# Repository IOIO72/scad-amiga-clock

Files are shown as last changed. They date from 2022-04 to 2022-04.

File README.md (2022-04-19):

# Amiga Clock (3 June 2021)
by IOIO72 aka Tamio Patrick Honma (https://honma.de)

## Description

Amiga Clock is an adaptation of Clock V2.15 from Amiga Workbench 1.2.

You can attach this 3D print to a clock movement to experience the physical version of an iconic program from the digital past.

The model is customizable and can be adapted to any clockwork and size - down to wristwatches. It's even possible to print static versions of different time settings, i.e. to create opening times signs.

For those, who don't want to create a customized version, here's the clockwork, I used for this project:
https://www.amazon.de/gp/product/B08RNJ5SYK/

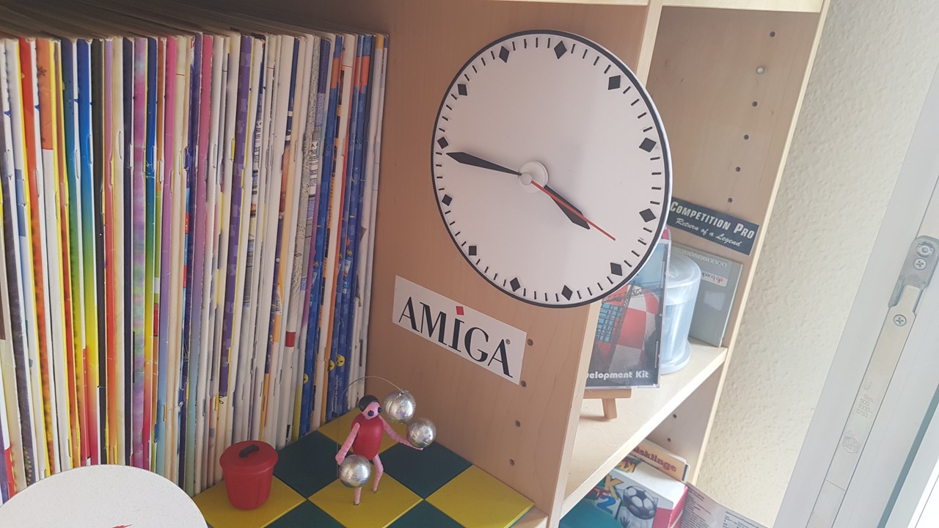
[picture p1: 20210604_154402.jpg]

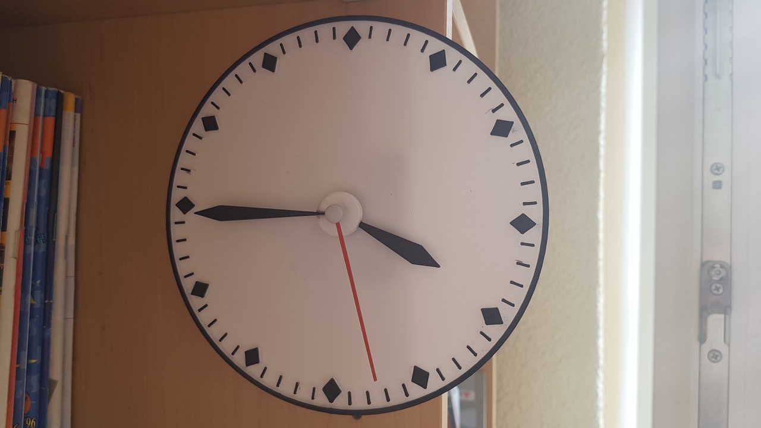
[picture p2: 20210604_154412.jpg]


### Where's the second hand?

Since the second hand has a small pin for mounting, it is not easy to print one that is accurate enough. The purchasable clockwork packages usually include a variety of hands from which you can choose. There should definitely be a second hand that is just a dash, like the one on the Amiga Clock. Use this second hand and paint it orange.

### Use OpenSCAD

1. **Download and install:** [OpenSCAD](http://openscad.org/) version 2021.01 or newer
2. **Download:** The *.scad file of this model.
3. **Start** OpenSCAD and **open** the *.scad file in it.
4. **Open the customizer** via the menu "Window/Customizer"

Now you can configure the model and use the `F5` key to render the preview of your changes.

#### Export your STL file

If you're done with your model settings, you can export the STL file:

1. Render the mesh by pressing the `F6` key.
2. Wait until the rendering is finished. This might take some minutes.
3. Export the STL file by pressing the `F7` key.

#### Optionally save your configuration

If you like to use your configuration as a template for further models, it's a good idea, to save your configuration:

1. Click the `+` symbol in the customizer, which you find beside the configuration selector drop-down in the second line of the customizer.
2. Give your configuration a name.

Use the drop-down menu to access your saved configurations.

### Trivia

The preset time refers to the time displayed on the Amiga clock icon.
The story behind this time is interesting:
http://theamigamuseum.com/amiga-kickstart-workbench-os/workbench/workbench-1-2/

### Smartwatch

If you want to wear an Amiga wristwatch as a Wear OS, Tizen or Apple Watch watchface, take a look at my WatchMaker creation:
https://getwatchmaker.com/watchface/amiga-wb-1-2

## Customizer

First of all: The customizer provides a test print model. This helps you to test your entered measurements without the need to print the whole model.

### Create a running Clock

If you like to create a running clock, you need to get a clockwork first.

By default the value `fastening_elements` in the `Modify Parts` section is turned on. If it's not, you should turn it on, as this switches on the part modifications to attach all clock part to the clockwork.

To adapt the Amiga Clock to your clockwork, you should use a caliper to measure it and enter the following values into the customizer:

#### Clockwork Hub

The following parameters are the most important ones:

1. In the lower part of the hub there is usually a thread where you screw the nut to fix the dial to the movement. Measure the diameter of the thread and enter the value to `hub_diameter`
2. Directly above the thread should be the wheel for the hour hand. Enter the diameter of this wheel in `hub_hours_diamater`.
3. And above the hour hand wheel should be the wheel for the minute hand. Enter this diameter in `hub_minutes_diamater`
4. On the back of the dial, you can adjust the diameter of an embossed alignment aid. My movement package included a rubber ring that fits in this embossment as a spacer to the movement case. Enter this value in `hub_embossment`.

#### Alignment helpers

To align the clockwork enclosure to the clock face, the enclosure offers four small pins - at least the one I've used. If your one doesn't provide these pins, you can set the value `pin_diameter` to zero.

If you like to use the pins, you should measure the diameter of one pin and enter the value in `pin_diameter`.

As the pin sticks into the backside of the clock face, you should enter the depth of the pin in `pin_depth`.

The positions of the pins should be measured from the center of the hub to each horizontal and vertical positions in the following order in the main brackets of `pin_positions `:

1. the values of the **left top pin** are entered in the the values of the **left top pin** are entered in the first bracket..
2. the values of the **right top pin** are entered in the **second bracket**.
3. the values of the **right bottom pin** are entered in the **third bracket**.
4. the values of the **left bottom pin** are entered in the **fourth bracket**.

#### Test your entered measurements

The accuracy of the entered values not only depend on the measurement itself, but also on the used filament, your slicer settings and the printer setup. Therefore, Amiga Clock provides test parts, which you can print without the need to print the large clock face.

To do this, go to the section `Select Parts` and unselect all parts. Then go to the section `Test Parts` and enable `measurements_test_parts`.

### Design your Clock

The main setting to design your clock, is the diameter of the clock face. Enter the value in `face_diamater`.

Additionally you can change the depth of the clock face in `face_base_depth`.

If you like to print the clock face base apart from the clock face content, which are the minutes lines and hours rhombuses, you can set an emboss depth value in `emboss_depth`. This embosses the content in the clock face base, which helps you to glue the elements accurate onto the clock face base.

#### Change the appearance of the Clock Face Content

You can tweak the depth, border size, content margin, minutes line size and hours rhombus size of the clock face in the section `Clock Face Content`. You can do this to personalize the content design. You need to do this, if you use a very small or large clock face diameter.

#### Configure Clock Hands

You can change the Clock Hands in depth in `hands_depth` . Note, that the minute hand uses half of the depth for the mount ring.

You can set the margin from hours rhombus' to the tip of the minute hand in `hands_margin`.

You can adjust the heights of the hands to affect how thin or wide they appear in `hour_hand_height` and `minute_hand_height`.

If you've activated the `fastening_elements`, both clock hands will provide an attachment ring, which refer to the diameters of the hub settings. To defined the size if this ring, you can change it in `hands_mount_ring_border_size `.

If you like to print a static version of the Amiga Clock, you can change the displayed time in `clock_time_hour` and `clock_time_minute`.

### Export Parts

Depending on your plan, how to attach the parts of the clock together, you can select and combine the parts as you like. Here are the usual combinations:

* If you like to export parts for a **real clockwork**, you have to **enable** `fastening_elements` and select and export the parts in the following combinations:
  * Select **minute hand** only, press F6, wait until render finishes and press F7 to export the STL.
  * Select **hour hand** only, press F6, wait until render finishes and press F7 to export the STL.
  * Select the **clock face base and clock face content together**, press F6, wait until render finishes and press F7 to export the STL.
* If you like to use **white filament** for the clock face base and **black filament** for the clock face content on a single extruder printer, you can export them separately and glue them together.
* If you like to export a **static version** of the clock,  **disable** `fastening_elements`, set your desired time in `clock_time_hour` and `clock_time_minute` and export **all parts together**.

# Mount the Clock

## Use test parts

To verify your measurements and the print settings, use the test parts.

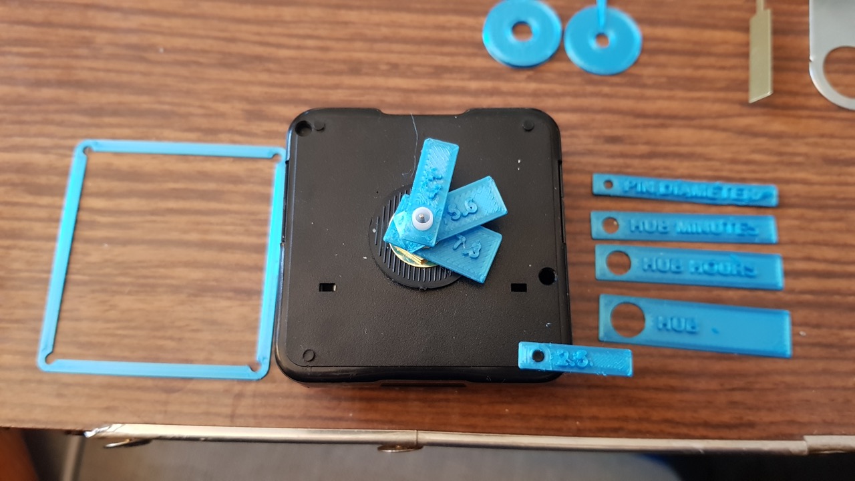
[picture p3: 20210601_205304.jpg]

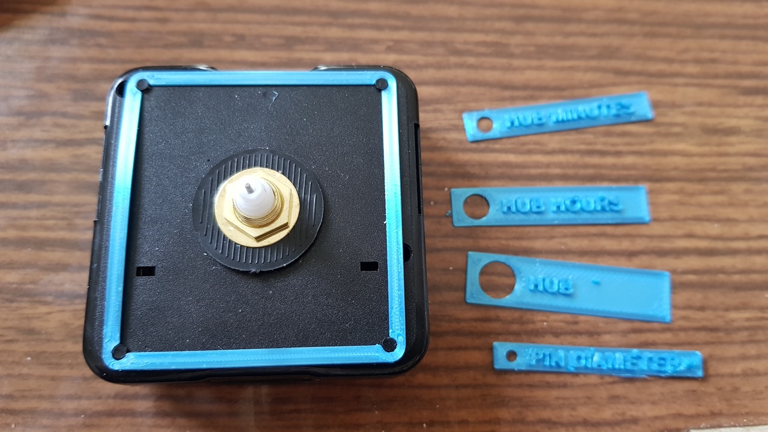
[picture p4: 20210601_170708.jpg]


## Attach parts

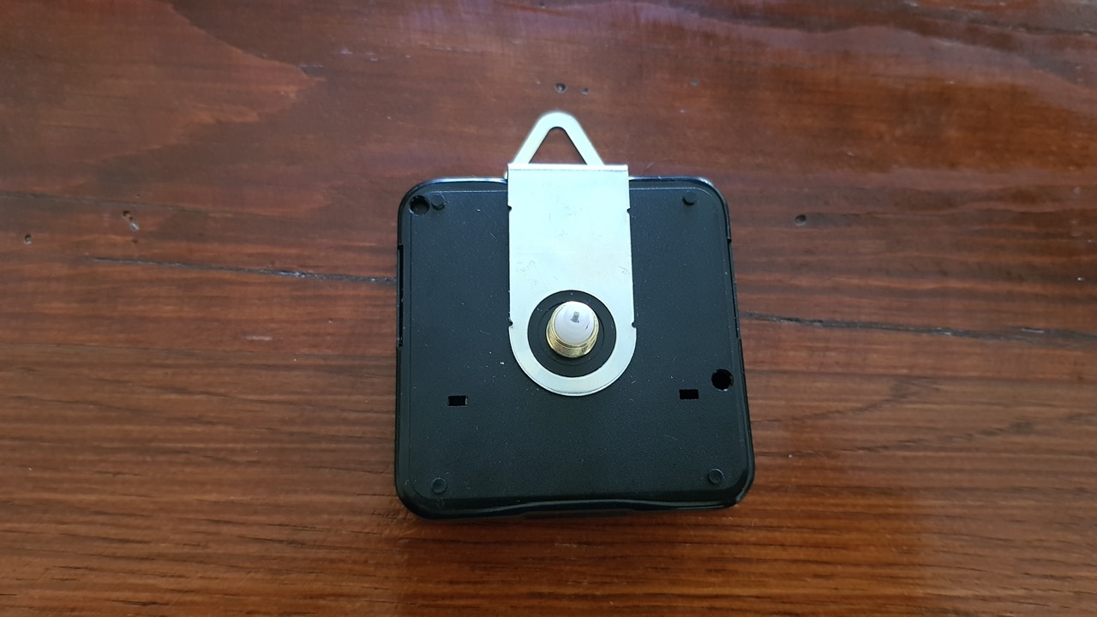
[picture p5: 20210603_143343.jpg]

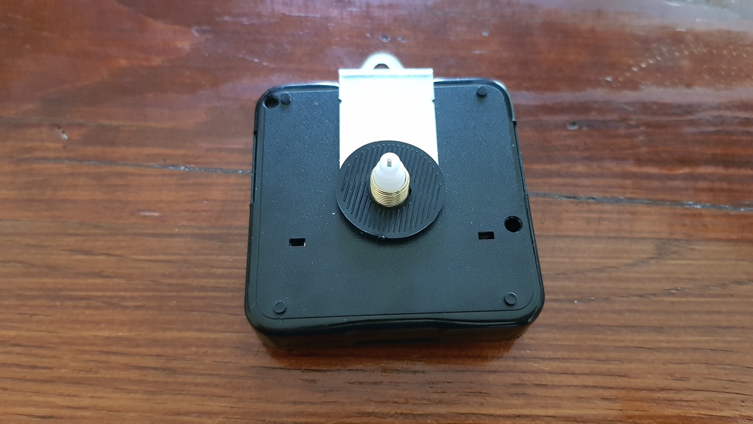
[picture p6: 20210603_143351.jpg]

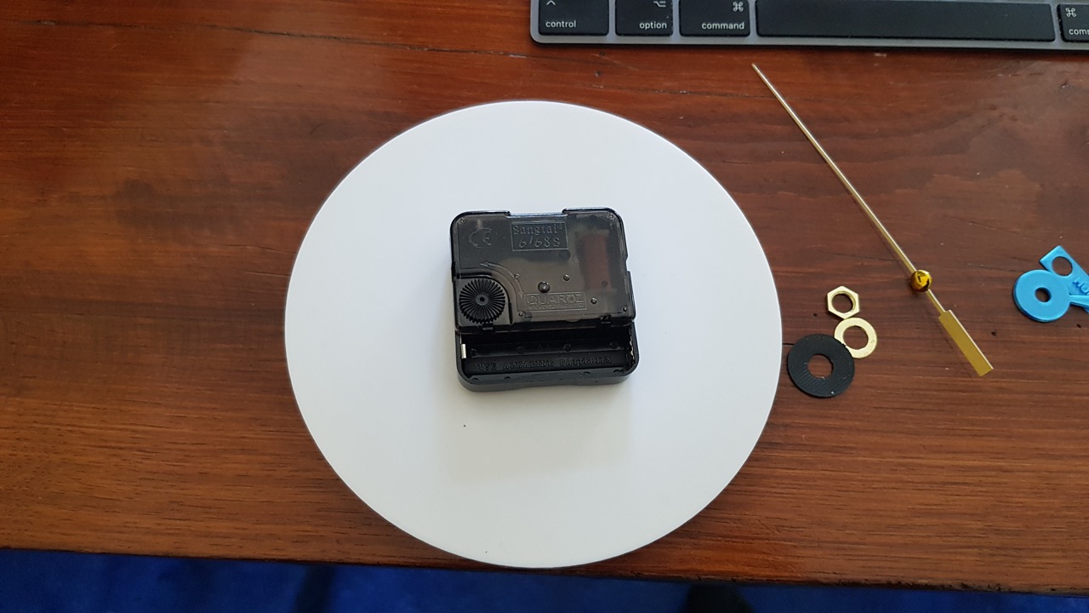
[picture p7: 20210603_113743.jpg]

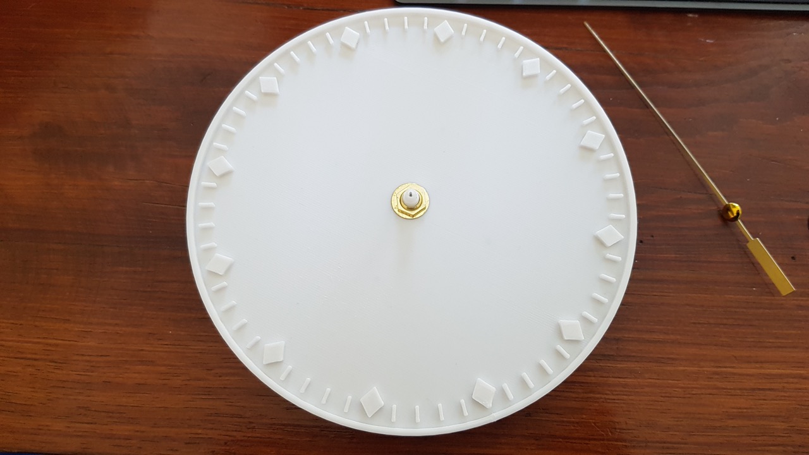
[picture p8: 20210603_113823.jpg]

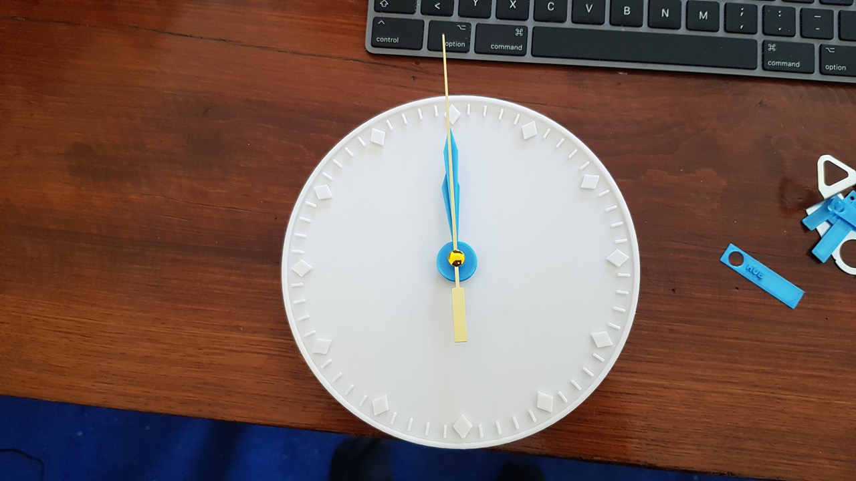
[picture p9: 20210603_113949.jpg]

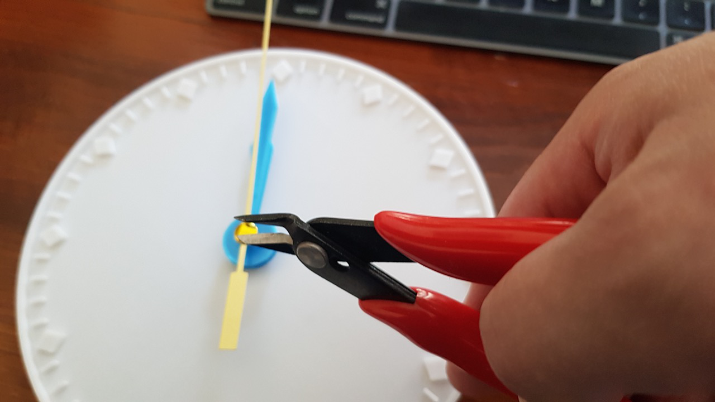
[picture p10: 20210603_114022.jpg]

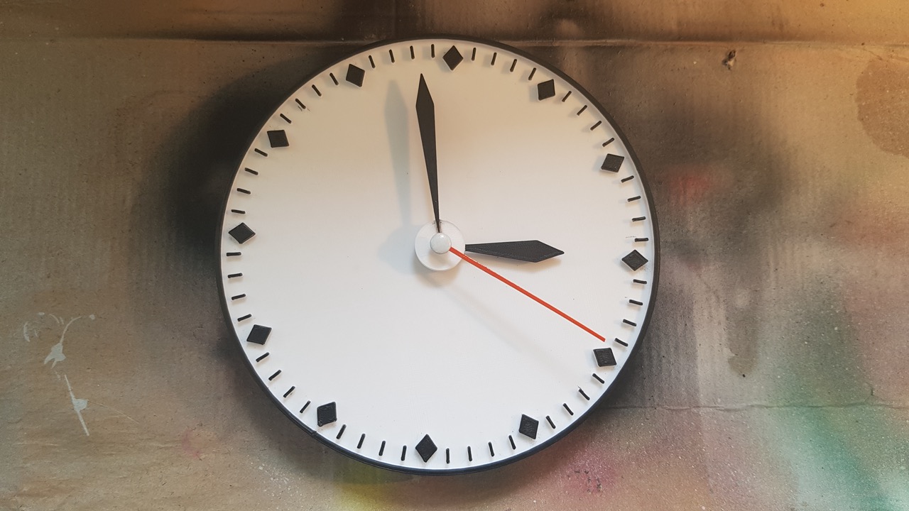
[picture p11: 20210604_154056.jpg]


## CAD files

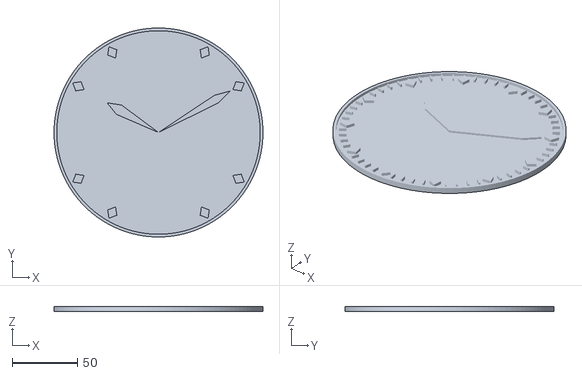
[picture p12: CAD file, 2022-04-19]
amiga-clock_static-complete.stl
160.0 x 160.0 x 4.20

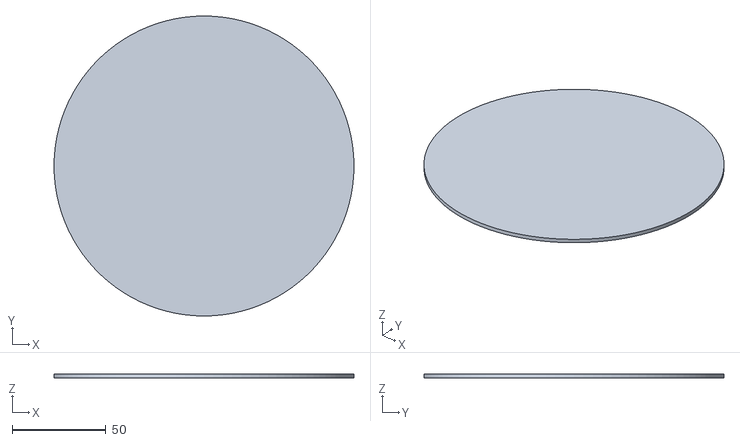
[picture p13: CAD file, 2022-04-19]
amiga-clock_static-base.stl
160.0 x 160.0 x 2.10

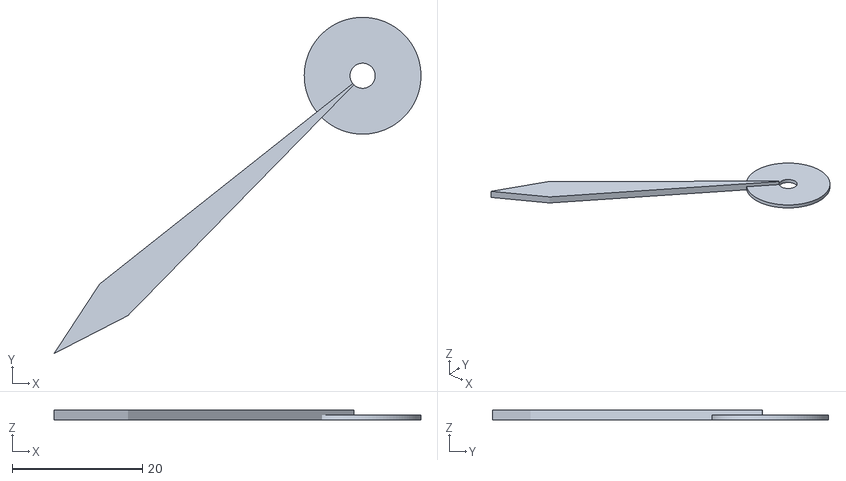
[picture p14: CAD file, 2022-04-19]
amiga-clock_minute-hand.stl
56.2 x 51.5 x 1.50

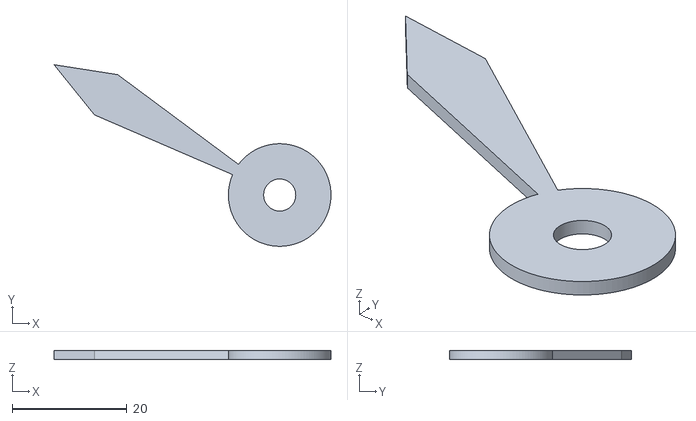
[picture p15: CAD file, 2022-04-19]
amiga-clock_hour-hand.stl
48.3 x 31.7 x 1.50

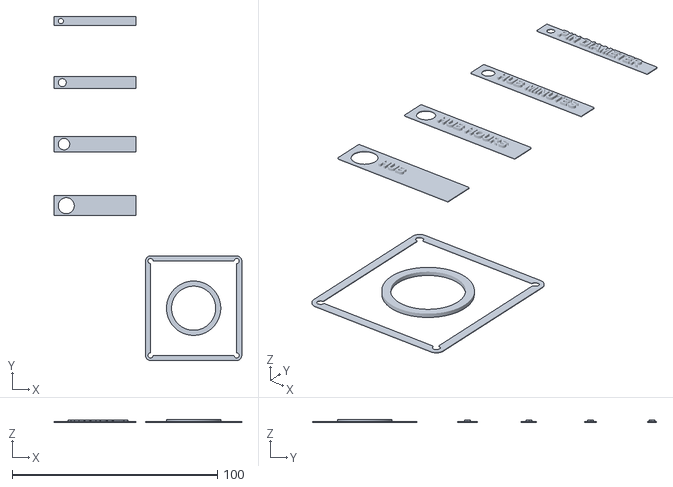
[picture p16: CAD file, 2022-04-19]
amiga-clock_test-parts.stl
91.5 x 167.8 x 1.25

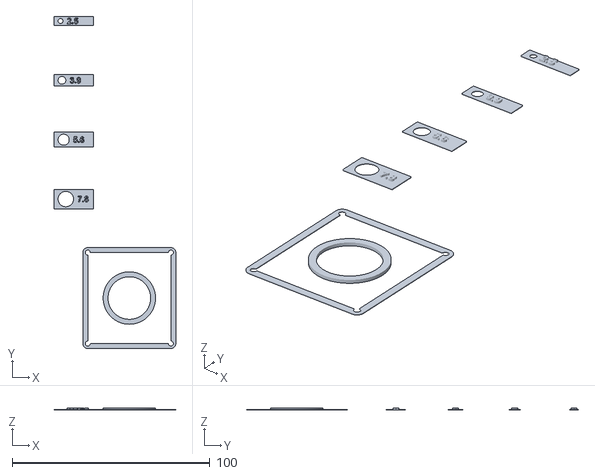
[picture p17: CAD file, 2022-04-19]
amiga-clock_test-parts_values.stl
61.5 x 167.8 x 1.25

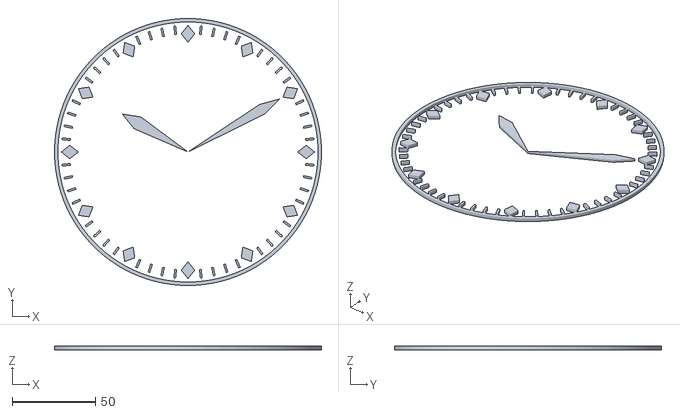
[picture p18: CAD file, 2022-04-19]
amiga-clock_static-content-hands.stl
160.0 x 160.0 x 2.10

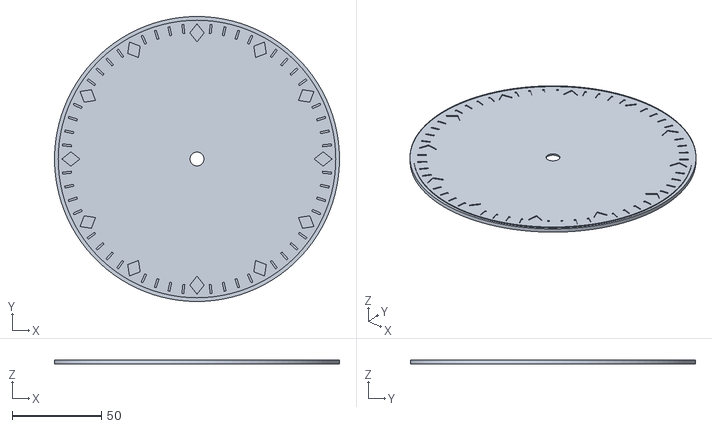
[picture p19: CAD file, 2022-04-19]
amiga-clock_base.stl
160.0 x 160.0 x 2.10

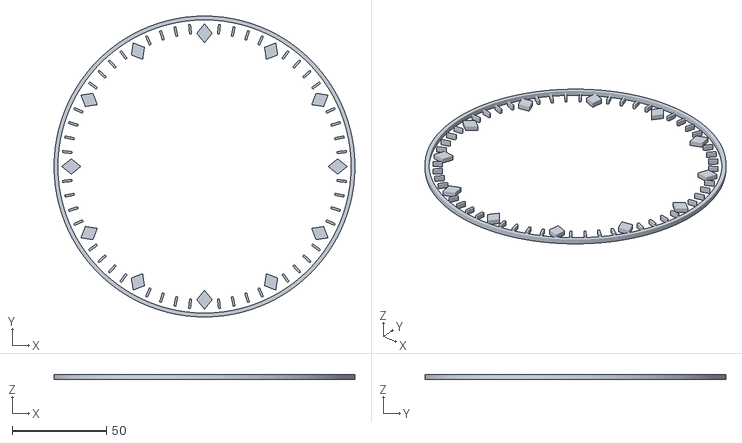
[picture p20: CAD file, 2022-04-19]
amiga-clock_content.stl
160.0 x 160.0 x 2.60

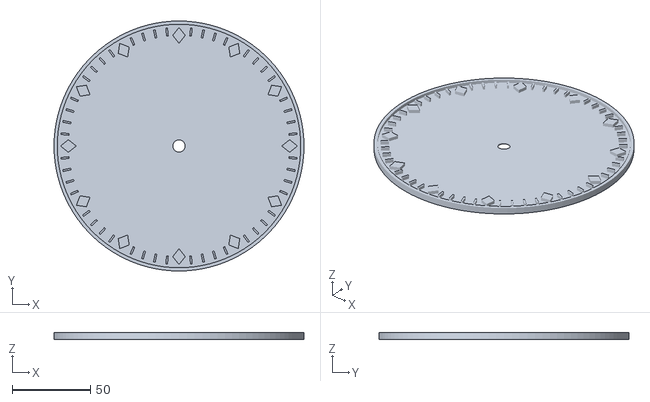
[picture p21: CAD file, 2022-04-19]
amiga-clock_face.stl
160.0 x 160.0 x 4.20

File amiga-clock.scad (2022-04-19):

/*
Amiga Clock (3 June 2021)
by IOIO72 aka Tamio Patrick Honma

Based on Clock V2.15 from Amiga Workbench 1.2.

This work is licensed under the Creative Commons Attribution-NonCommercial-ShareAlike 4.0 International License. To view a copy of this license, visit http://creativecommons.org/licenses/by-nc-sa/4.0/ or send a letter to Creative Commons, PO Box 1866, Mountain View, CA 94042, USA.


Used clockwork for this project:
https://www.amazon.de/gp/product/B08RNJ5SYK/

You can use any other and enter your measurements.

---

Where's the second hand?

Since the second hand has a small pin for mounting, it is not easy to print one that is accurate enough. The purchasable clockwork packages usually include a variety of hands from which you can choose. There should definitely be a second hand that is just a dash, like the one on the Amiga Clock. Use this second hand and paint it orange.


Trivia

The preset time refers to the time displayed on the Amiga clock icon.
The story behind this time is interesting:
http://theamigamuseum.com/amiga-kickstart-workbench-os/workbench/workbench-1-2/


Smartwatch

If you want to wear an Amiga wristwatch as a Wear OS watchface, take a look at my WatchMaker creation:
http://bulletin-board.de/watchfaces/portfolio/amiga-wb-1-2/

*/


/* [Clockwork Enclosure Pins to align clockwork with clock face] */

// Dimameter of the pins
pin_diameter = 2.5;

// Depth of the pins (should be less than face_base_depth)
pin_depth = 1.25;

// Positions of the pins (left top, right top, right bottom, left bottom)
pin_positions = [
  [-21,-23], [21,-23],
  [21,23], [-21,23]
];


/* [Clockwork Hub] */

// Hub diameter
hub_diameter = 7.8;

// Hours hub diameter
hub_hours_diamater = 5.6;

// Minutes hub diameter
hub_minutes_diamater = 3.9;

// Backward hub embossment
hub_embossment = 21.5;


/* [Clock Face Base] */

// Clock face diameter
face_diamater = 160;

// Clock face base depth (should be larger than pin_depth)
face_base_depth = 2.1;

// Emboss depth of content in base
emboss_depth = 0.5;


/* [Clock Face Content] */

// Clock face content depth
face_content_depth = 2.1;

// Clock face border
face_border_size = 2.1;

// Clock face content margin
face_content_margin = 4.1;

// Minutes size (rectangle)
minutes_size = [5.1,1.1];

// Hours size (rhombus)
hours_size = [10.1,8.1];


/* [Clock Hands] */

// Hands depth
hands_depth = 1.5;

// Hands margin from hours rhombus'
hands_margin = 2.1;

// Hour hand height
hour_hand_height = 8.1;

// Minute hands height
minute_hand_height = 6.5;

// Clock time hour
clock_time_hour = 11; // [1:12]

// Clock time minute
clock_time_minute = 38; // [0:59]

// Mount ring border size
hands_mount_ring_border_size = 10.1;


/* [Modify Parts] */

// Fastening elements
fastening_elements = true;


/* [Select Parts] */

// Clock face base
clock_face_base = true;

// Clock face content
clock_face_content = true;

// Clock hours hand
clock_hour_hand = true;

// Clock minutes hand
clock_minute_hand = true;


/* [Test Parts] */

// Measurements test parts
measurements_test_parts = false;

// Test parts label tag width
test_tag_width = 40;

// Tags with values instead of labels
test_tag_values = false;


/* [Advanced] */

// Number of fragments
$fn = 100; // [1:200]

// Debug mode
debug = false;


/* [Hidden] */

face_inner_diameter = face_diamater - 2 * face_border_size;
face_content_diameter = face_inner_diameter - face_content_margin;
hands_content_diameter = face_content_diameter - hours_size[0] * 2 - hands_margin * 2;
minute_hand_length = hands_content_diameter / 2;
hour_hand_length = minute_hand_length / 1.4;

test_parts = [
  [hub_diameter, "HUB"],
  [hub_hours_diamater, "HUB HOURS"],
  [hub_minutes_diamater, "HUB MINUTES"],
  [pin_diameter, "PIN DIAMETER"]
];


module ring(_diameter, _inner_diameter) {
  difference() {
    circle(d = _diameter);
    circle(d = _inner_diameter);
  };
};

module rhombus(_width, _inbetween_width, _height) {
  polygon([
    [0, 0],
    [_inbetween_width, _height / 2],
    [_width, 0],
    [_inbetween_width, - _height / 2]
  ]);
};

module face_content() {

  // Border
  ring(face_diamater, face_inner_diameter);

  // Minutes
  for(i = [1:60]) {
    if (i % 5 != 0) {
      rotate([0, 0, i * 6])
      translate([face_content_diameter / 2 - minutes_size[0] / 2, 0, 0])
      square(minutes_size, center = true);
    };
  };

  // Hours
  for (i = [1:12]) {
    rotate([0, 0, i * 30])
    translate([face_content_diameter / 2 - hours_size[0], 0, 0])
    rhombus(hours_size[0], hours_size[0] / 2, hours_size[1]);
  };
};

module clock_hand(
  _hand_length,
  _hand_inbetween_width,
  _hand_height,
  _hub_diamater,
  _hub_mount_diamater,
  _with_fastening
) {
  difference() {
    union() {
      rhombus(_hand_length, _hand_inbetween_width, _hand_height);
      if (_with_fastening) {
        ring(
          _hub_mount_diamater,
          _hub_diamater
        );
      };
    };
    if (fastening_elements) {
      circle(d=_hub_diamater);
    };
  };
};


// Face Base
module alignment_pins() {
  for (i = pin_positions) {
    rotate([0, 0, 180]) {
      translate(i) {
        circle(d = pin_diameter);
        if (debug) {
          text(str(i), size = 6);
        };
      };
    };
  };
};

if (clock_face_base) {
  color(debug ? "#66aa99" : "#ffffff") {
    if (fastening_elements) {
      difference() {
        linear_extrude(face_base_depth) circle(d = face_diamater);
        linear_extrude(face_base_depth) circle(d = hub_diameter);

        // Alignment Pins
        linear_extrude(pin_depth) {
          alignment_pins();
          circle(d = hub_embossment);
        };
        
        // Emboss Face Content
        translate([0, 0, face_base_depth - emboss_depth]) {
          linear_extrude(emboss_depth) face_content();
        };
      };
    } else {
      linear_extrude(face_base_depth) circle(d = face_diamater);
    };
  };
};


// Face Content
if (clock_face_content) {
  color(debug ? "#6699bb" : "#000000") {
    translate([0, 0, fastening_elements ? face_base_depth - emboss_depth : face_base_depth]) {
      linear_extrude(fastening_elements ? face_content_depth + emboss_depth : face_content_depth) {
        face_content();
      };
    };
  };
};

// Hours Hand
if (clock_hour_hand) {
  color(debug ? "#cc6699" : "#000000") {
    translate([0, 0, fastening_elements ? face_base_depth + face_content_depth : face_base_depth]) {
      rotate([0, 0, 90 - clock_time_hour * 30 - clock_time_minute / 2]) {
        linear_extrude(hands_depth) {
          clock_hand(
            hour_hand_length,
            hour_hand_length / 1.3,
            hour_hand_height,
            hub_hours_diamater,
            hub_diameter + hands_mount_ring_border_size,
            fastening_elements
          );
        };
      };
    };
  };
};


// Minutes Hand
module minute_hand_part(_with_fastening) {
  linear_extrude(hands_depth / 2) {
    clock_hand(
      minute_hand_length,
      minute_hand_length / 1.24,
      minute_hand_height,
      hub_minutes_diamater,
      hub_diameter + hands_mount_ring_border_size,
      _with_fastening
    );
  };
};

if (clock_minute_hand) {
  color(debug ? "#dd9966" : "#000000") {
    translate([0, 0, fastening_elements ? face_base_depth + face_content_depth + hands_depth : face_base_depth]) {
      rotate([0, 0, 90 - clock_time_minute * 6]) {
        minute_hand_part(fastening_elements);
        translate([0, 0, hands_depth / 2]) {
          minute_hand_part(false);
        };
      };
    };
  };
};


// Measurements test parts
module test_part_tag(tag = [10, "undefined"]) {
  linear_extrude(0.4) {
    difference() {
      square([test_tag_width, tag[0] + 2], center = true);
      translate([- test_tag_width / 2 + tag[0] / 2 + 2, 0, 0]) {
        circle(d = tag[0]);
      };
    };
  };
  translate([- test_tag_width / 2 + tag[0] + 4, 0, 0.4]) {
    linear_extrude(0.8)
    text(test_tag_values ? str(tag[0]) : tag[1], size = 3, font = "Arial:style=Bold", halign="left", valign="center");
  };
 
};

if (measurements_test_parts) {
  translate([face_diamater + 5, 0, 0]) {
    for (i = [0 : len(test_parts) - 1]) {
      translate([0, i * 30, 0])
      test_part_tag(test_parts[i]);
    };
  
    // Alignment Pins
    translate([test_tag_width + 8, -50, 0]) {
      linear_extrude(0.4) {
        difference() {
          offset(pin_diameter) rotate([0, 0, 180]) polygon(pin_positions);
          rotate([0, 0, 180]) polygon(pin_positions);
          alignment_pins();
        };
      };
    };
    
    // Hub embossment
    translate([test_tag_width + 8, -50, 0]) {
      linear_extrude(pin_depth) {
        difference() {
          offset(pin_diameter) circle(d = hub_embossment);
          circle(d = hub_embossment);
        };
      };
    };

  };
};
